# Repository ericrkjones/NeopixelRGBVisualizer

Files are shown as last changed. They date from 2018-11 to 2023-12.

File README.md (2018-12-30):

# NeopixelRGBVisualizer
A Neopixel strand visualizer for an audio input that maps frequency distribution to color.  

# Modes
The device has multiple display modes.  To change modes, press the "M" button.

# Settings
To change the settings, press and hold the "M" button for 3 seconds.  The first light in the strand will change color to indicate the setting that will be adjusted.  Press the "M" button again to cycle to the next setting.  After cycling through all the setting modes, the settings will be stored for the next time you plug the device in.  

## Length
When the light is red, press the plus and minus buttons to change the length of the strand.  The strand is made of Neopixels, so it can be cut short (while the power is off) if you need it to be shorter.  To reset to the default 50 lights, press and hold both the plus and minus button at the same time.  

## Gain
When the light is green, press the plus and minus buttons to change the input gain.  Adjusting the gain up is possible but not recommended because the noise will be amplified.  Adjusting the noise down may be necessary.  If the appropriate gain cannot be set, external hardware may be required.  To reset to the default gain, press and hold both the plus and minus button at the same time.

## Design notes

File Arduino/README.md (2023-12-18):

# Hardware notes

The manufactured versions of this board use an atmega328p**b** not the typical atmega328p, you will therefore need to make sure your programmer knows this. If you are using `avrdude` you can do this wihh the parameter `-patmega328pb` for example `/usr/bin/avrdude -C/etc/avrdude.conf -v -patmega328pb -cstk500v1 -P/dev/ttyACM0 -b19200 -Uflash:w:<PATH TO HEX FILE>/MSGEQ7NeopixelTree4.ino.hex:i` or in the arduino IDE add [this](https://github.com/watterott/ATmega328PB-Testing) board file.

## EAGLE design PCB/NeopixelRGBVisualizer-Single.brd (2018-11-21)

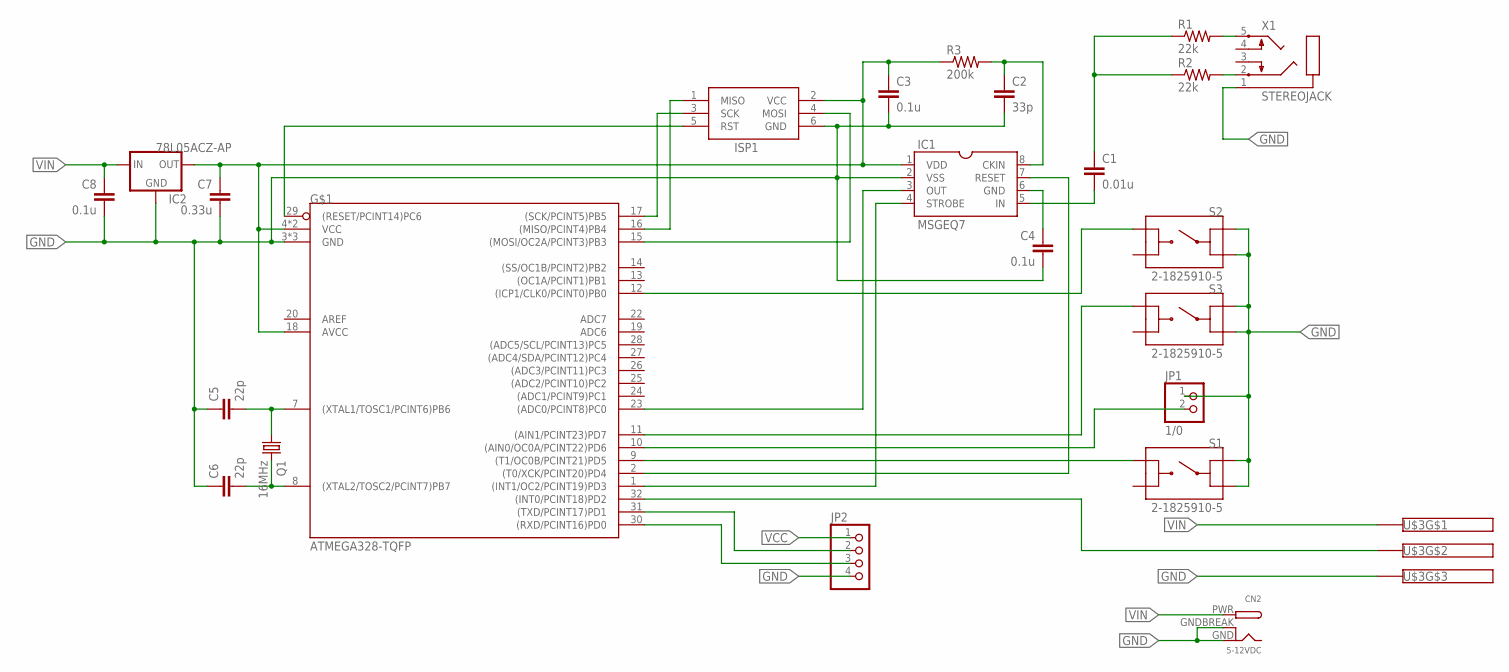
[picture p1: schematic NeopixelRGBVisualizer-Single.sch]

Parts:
C1: 0.01u; C0805
C2: 33p; C0805
C3, C4, C8: 0.1u; C0805
C5, C6: 22p; C0805
C7: 0.33u; C0805
CN2: 5-12VDC; DCJACK_2MM_PTH
IC1: MSGEQ7; DIL08
IC2: 78L05ACZ-AP; 78LXX
ISP1: AVRISP-6; AVRISP
JP1: 1/0; 1X02-ROUND
JP2: PINHD-1X4/OCT; 1X04-OCT
Q1: 16MHz; CTS406
R1, R2: 22k; M0805
R3: 200k; M0805
S1, S2, S3: 2-1825910-5; SW_2-1825910
U$1: ATMEGA328-TQFP; 32M1-A
U$3: 0039303035; 4.2MM-3PIN
X1: STEREOJACK; STX3100

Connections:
GND: C2.2, C3.2, C4.2, C5.1, C6.1, C7.2, C8.2, CN2.GND, CN2.GNDBREAK, IC1.2 (VSS), IC2.GND, ISP1.6 (GND), JP1.1, JP2.4, S1.1, S1.3, S2.1, S2.3, S3.1, S3.3, U$1.3 (GND), U$1.5 (GND), U$1.21 (GND), U$3.P$3, X1.1
MSGEQ7_OUT: IC1.3 (OUT), U$1.23 ((ADC0/PCINT8)PC0)
MSGEQ7_RESET: IC1.7 (RESET), U$1.2 ((T0/XCK/PCINT20)PD4)
MSGEQ7_STROBE: IC1.4 (STROBE), U$1.1 ((INT1/OC2/PCINT19)PD3)
unnamed: ISP1.3 (SCK), U$1.17 ((SCK/PCINT5)PB5)
unnamed: ISP1.5 (RST), U$1.29 ((RESET/PCINT14)PC6)
unnamed: ISP1.1 (MISO), U$1.16 ((MISO/PCINT4)PB4)
unnamed: ISP1.4 (MOSI), U$1.15 ((MOSI/OC2A/PCINT3)PB3)
unnamed: C4.1, IC1.6 (GND)
unnamed: S3.2, U$1.11 ((AIN1/PCINT23)PD7)
unnamed: C1.2, IC1.5 (IN)
unnamed: R2.2, X1.2
unnamed: C2.1, IC1.8 (CKIN), R3.2
unnamed: R1.2, X1.5
unnamed: C5.2, Q1.1, U$1.7 ((XTAL1/TOSC1/PCINT6)PB6)
unnamed: C6.2, Q1.3 (2), U$1.8 ((XTAL2/TOSC2/PCINT7)PB7)
unnamed: C1.1, R1.1, R2.1
unnamed: U$1.32 ((INT0/PCINT18)PD2), U$3.P$2
unnamed: S2.2, U$1.12 ((ICP1/CLK0/PCINT0)PB0)
unnamed: JP1.2, U$1.10 ((AIN0/OC0A/PCINT22)PD6)
unnamed: S1.2, U$1.9 ((T1/OC0B/PCINT21)PD5)
RX: JP2.3, U$1.30 ((RXD/PCINT16)PD0)
TX: JP2.2, U$1.31 ((TXD/PCINT17)PD1)
VCC: C3.1, C7.1, IC1.1 (VDD), IC2.OUT, ISP1.2 (VCC), JP2.1, R3.1, U$1.4 (VCC), U$1.6 (VCC), U$1.18 (AVCC)
VIN: C8.1, CN2.PWR, IC2.IN, U$3.P$1

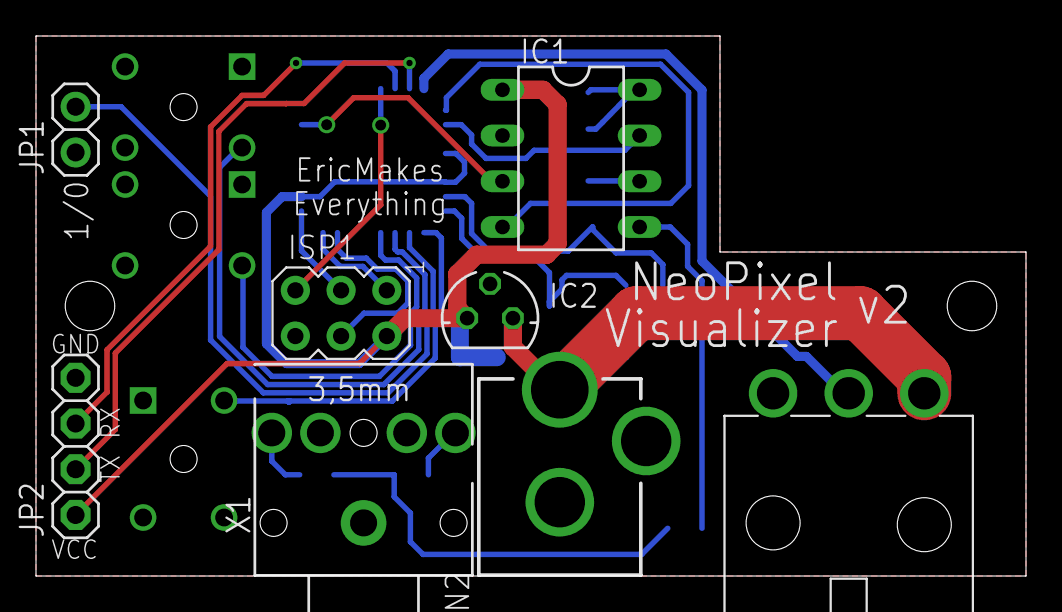
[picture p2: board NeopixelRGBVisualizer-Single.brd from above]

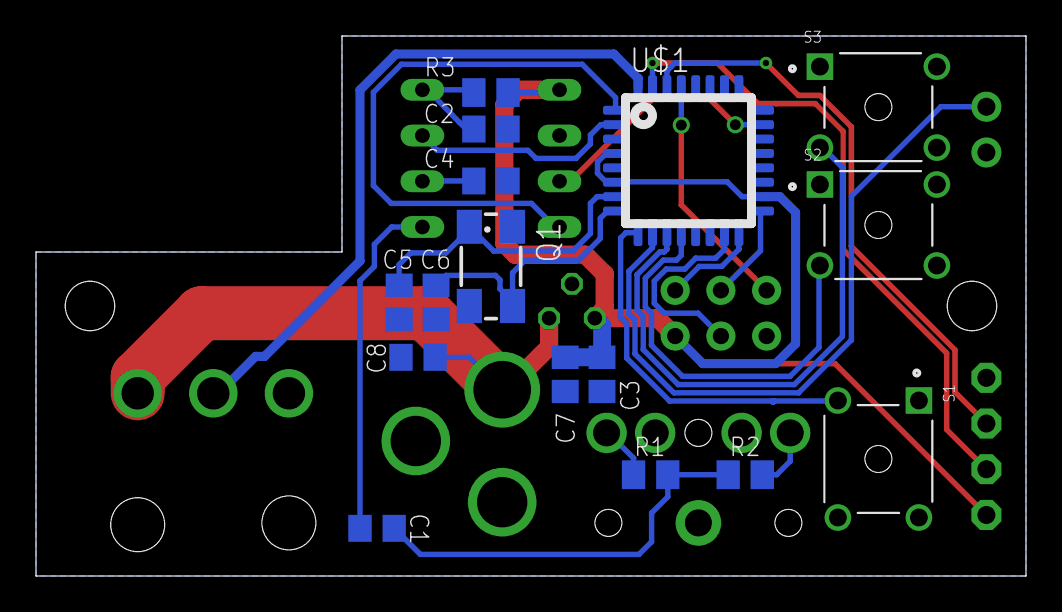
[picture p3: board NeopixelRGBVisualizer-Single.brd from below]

Board: 2 copper layers, 55.0 x 30.0 mm, 24 parts (16 on the bottom side), 25 nets.

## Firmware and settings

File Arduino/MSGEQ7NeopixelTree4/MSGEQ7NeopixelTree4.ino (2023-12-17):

// Import NicoHood's MSGEQ7 driver
#include <MSGEQ7.h>
#include <EEPROM.h>
//
#include "MSGEQ7NeopixelTree4.h"
/*
  Persistant customization variables
*/

#define CONFIG_DELAY 50
// Length of the Neopixel display
unsigned long length = 50;
const unsigned long defaultlength = 50;
const int length_eepromaddress = 0;
// Global input linear gain as a fraction of 255
unsigned long gain = 240;
const int gain_eepromaddress = 4;
const long defaultgain = 240;
// Maximum and minimum brightness per channel
byte maxbrightness = 100; 
const byte defaultmaxbrightness = 100;
byte minbrightness = 5;
const byte defaultminbrightness = 5;
// Color 1 for use in fixed-color displays, RGB order
word hue1 = 0;
const int defaulthue1 = 0;
// Color 2 for use in fixed color displays, RGB order
word hue2 = 255;
const byte defaulthue2 = 255;
/*
  Permutation index of RGB for all-color displays.
  0: RGB
  1: GBR
  2: BRG
  3: RBG
  4: GRB
  5: BGR
  Notice that 0-2 are rotated RGB order and 3-5 are rotated RBG order
  So, for any moving displays that use a fade through all colors,
  all that matters is those ranges.
*/
byte rgbpermutationindex;
const byte defaultrgbperumtationindex = 0;
// Speed for scrolling displays in units of milliseconds/dot
byte speed;
const byte defaultspeed = 30;
// 0-index point for bar-style displays
unsigned long startpoint;
const long defaultstartpoint = 0;
// Operating mode
byte mode = 0;

// Global variables

// Define Neopixel connection
Adafruit_NeoPixel strip = Adafruit_NeoPixel(length, STRIP_PIN, NEO_RGB + NEO_KHZ800);

// Define MSGEQ7 connection
CMSGEQ7<MSGEQ7_SMOOTH, MSGEQ7_PINRESET, MSGEQ7_PINSTROBE, MSGEQ7_PINDCIN> MSGEQ7;

// Frequency volume values
byte freqVolume[MSGEQ7_FREQCOUNT];
long meanVolume = 0;

// Button variables
bool button_mode;
bool button_mode_last = 0;
bool button_mode_rising = 0;
bool button_mode_falling = 0;
unsigned long button_mode_start_time = 0;
unsigned long button_mode_held_time;
bool button_minus;
bool button_minus_last = 0;
bool button_minus_rising = 0;
bool button_minus_falling = 0;
unsigned long button_minus_start_time = 0;
unsigned long button_minus_held_time;
bool button_plus;
bool button_plus_last = 0;
bool button_plus_rising = 0;
bool button_plus_falling = 0;
unsigned long button_plus_start_time = 0;
unsigned long button_plus_held_time;
bool button_custom;
bool button_custom_last = 0;
bool button_custom_rising = 0;
bool button_custom_falling = 0;
unsigned long button_custom_start_time = 0;
unsigned long button_custom_held_time;
unsigned long config_fastadd_start_time = 0;
unsigned long current_time = 0;

void readbuttons() {
  button_mode = ! digitalRead(BUTTON_MODE);
  button_minus = ! digitalRead(BUTTON_MINUS);
  button_plus = ! digitalRead(BUTTON_PLUS);
  button_custom = ! digitalRead(BUTTON_CUSTOM);
  // Set rising edge booleans
  if (button_mode && ! button_mode_last) {
    button_mode_rising = 1;
  } else {
    if (!button_mode && button_mode_last) {
      button_mode_falling = 1;
    } else {
      button_mode_rising = 0;
      button_mode_falling = 0;
    }
  }
  if (button_minus && ! button_minus_last) {
    button_minus_rising = 1;
  } else {
    if (!button_minus && button_mode_last) {
      button_mode_falling = 1;
    } else {
      button_minus_rising = 0;
      button_minus_falling = 0;
    }
  }
  if (button_plus && ! button_plus_last) {
    button_plus_rising = 1;
  } else {
    if (!button_plus && button_mode_last) {
      button_mode_falling = 1;
    } else {
      button_plus_rising = 0;
      button_plus_falling = 0;
    }
  }
  if (button_custom && ! button_custom_last) {
    button_custom_rising = 1;
  } else {
    if (!button_custom && button_mode_last) {
      button_mode_falling = 1;
    } else {
      button_custom_rising = 0;
      button_custom_falling = 0;
    }
  }
  // Set the last time that the buttons were not pressed
  // Calculate difference in time between now and when buttons were last not pressed
  if (button_mode) {
    button_mode_held_time = current_time - button_mode_start_time;
  } else {
    button_mode_start_time = current_time;
    button_mode_held_time = 0;
  }
  if (button_minus) {
    button_minus_held_time = current_time - button_minus_start_time;
  } else {
    button_minus_start_time = current_time;
    button_minus_held_time = 0;
  }
  if (button_plus) {
    button_plus_held_time = current_time - button_plus_start_time;
  } else {
    button_plus_start_time = current_time;
    button_plus_held_time = 0;
  }
  if (button_custom) {
    button_custom_held_time = current_time - button_custom_start_time;
  } else {
    button_custom_start_time = current_time;
    button_custom_held_time = 0;
  }
  // Set loop variables
  button_mode_last = button_mode;
  button_minus_last = button_minus;
  button_plus_last = button_plus;
  button_custom_last = button_custom;
}

byte coerceToByte(long x) {
  if (x < 0) {
    x = 0;
  } else {
    if (x > 255) {
      x = 255;
    }
  }
  return byte(x);
}

unsigned long eepromReadLong(int address) {
  long value;
  for (int i = 0; i < 4; i++) {
    value = value << 8;
    value += EEPROM.read(address + i);
  }
  return value;
}

void eepromWriteLong(int address, unsigned long value) {
  for (int i = 0; i < 4; i++) {
    EEPROM.update(address + 3 - i, value >> (i * 8));
  }
}

void updateFreqVolume() {
  for (int i = 0; i < MSGEQ7_FREQCOUNT; i++) {
#ifdef MSGEQ7_MAPNOISE
    freqVolume[i] = mapNoise(MSGEQ7.get(i));
#else
    freqVolume[i] = MSGEQ7.get(i);
#endif
  }
}

long getMeanVolume() {
  long y = (MSGEQ7.getVolume() + GAIN_OFFSET) * gain / 255;
  if (y < 0) {
    y = 0;
  }
  return y;
}

void readAudio() {
  updateFreqVolume();
  meanVolume = getMeanVolume();
}

void startNeopixels() {
  strip = Adafruit_NeoPixel(length, STRIP_PIN, NEO_RGB + NEO_KHZ800);
  strip.begin();
  strip.show();
}

// RGBVu functions:

int   rgbvu_red0   = 0;
int rgbvu_green0   = 0;
int  rgbvu_blue0   = 0;
int   rgbvu_red1[] = {70, 70, 30, 0, 0, 0, 0};
int rgbvu_green1[] = {0, 0, 40, 60, 40, 0, 0};
int  rgbvu_blue1[] = {0, 0, 0, 0, 30, 60, 60};

// RGB values
byte rgbvu_red = 0;
byte rgbvu_green = 0;
byte rgbvu_blue = 0;

long rgbvu_calculateColor(byte sample[], int color1[]) {
  long y = 0;
  for (int i = 0; i < MSGEQ7_FREQCOUNT; i++) {
    y += sample[i] * color1[i];
  }
  return y;
}

void rgbvu_normalizeColors() {
  long r = rgbvu_calculateColor(freqVolume, rgbvu_red1) / 255 + rgbvu_red0;
  long g = rgbvu_calculateColor(freqVolume, rgbvu_green1) / 255 + rgbvu_red0;
  long b = rgbvu_calculateColor(freqVolume, rgbvu_blue1) / 255 + rgbvu_red0;
  long sum = r + g + b;
  rgbvu_red = coerceToByte(maxbrightness * r / sum);
  rgbvu_green = coerceToByte(maxbrightness * g / sum);
  rgbvu_blue = coerceToByte(maxbrightness * b / sum);
}
void rgbvu_output() {
  for (int i = 0; i < length; i++) {
    if (i < meanVolume) {
      strip.setPixelColor(i, strip.Color(rgbvu_red, rgbvu_green, rgbvu_blue));
    } else {
      strip.setPixelColor(i, strip.Color(minbrightness, minbrightness, minbrightness));
    }
  }
}

void visualizer_rgbvu() {
  // 0th order polynomial coefficient
  // This is not broken out because, when the dependent terms are summed, that would waste time
  rgbvu_normalizeColors();
  rgbvu_output();
  strip.show();
}

void visualizer_config_rgbvu(byte color[]) {
  // 0th order polynomial coefficient
  // This is not broken out because, when the dependent terms are summed, that would waste time
  rgbvu_normalizeColors();
  rgbvu_output();
  strip.setPixelColor(0, strip.Color(color[0], color[1], color[2]));
  strip.show();
}

void setup() {
  // Set pinmode for buttons
  pinMode(BUTTON_MODE, INPUT_PULLUP);
  pinMode(BUTTON_MINUS, INPUT_PULLUP);
  pinMode(BUTTON_PLUS, INPUT_PULLUP);
  pinMode(BUTTON_CUSTOM, INPUT_PULLUP);

  //  // Read EEPROM
  length = eepromReadLong(length_eepromaddress);
  gain = eepromReadLong(gain_eepromaddress);

  if (length > 65534) {
    length = defaultlength;
    eepromWriteLong(length_eepromaddress, length);
  }
  if (gain > 1020) {
    gain = defaultgain;
    eepromWriteLong(gain_eepromaddress, gain);
  }

  
  // Start Neopixels
  startNeopixels();

  // Initialize MSGEQ7
  MSGEQ7.begin();
}


//Rainbow Wheel

unsigned int hue = 0;

// Input a value 0 to 255 to get a color value.
// The colours are a transition r - g - b - back to r.
uint32_t Wheel(unsigned int hue) {
  if (hue > 765) {
    hue -= 765;
  }
  if (hue < 255) {
    return strip.Color(normalizeColor(255 - hue), normalizeColor(hue), 0);
  }
  if (hue < 510) {
    hue -= 255;
    return strip.Color(0, normalizeColor(255 - hue), normalizeColor(hue));
  }
  hue -= 510;
  return strip.Color(normalizeColor(hue), 0, normalizeColor(255 - hue));
}

byte normalizeColor(byte color) {
  word colorout = color * maxbrightness / 255;
  return colorout;
}

void rainbow() {
  for (unsigned int i = 0; i < length; i++) {
    strip.setPixelColor(i, Wheel(length - i - 1 + hue));
  }
  strip.show();
  if (hue == 764) {
    hue = 0;
  } else {
    hue ++;
  }
  delay(10);
}

bool statedelay(unsigned long delaytime) {
  if (current_time - config_fastadd_start_time > delaytime) {
    config_fastadd_start_time = current_time;
    return true;
  } else {
    return false;
  }
}

void loop() {
  current_time = millis();
  bool newReading = MSGEQ7.read();
  readbuttons();
  if (newReading) {
    readAudio();
  }
  if (button_mode_held_time > 3000) {
    mode = 253;
  }
  switch (mode) {
    case 0:
      if (button_mode_rising) {
        mode ++;
      } else {
        if (newReading) {
          visualizer_rgbvu();
        }
      }
      break;
    case 1:
      if (button_mode_rising) {
        mode ++;
      } else {
        if (newReading) {
          rainbow();
        }
      }
      break;
    // Global Length Setting
    case 253:
      if (button_mode_rising) {
        mode ++;
      } else {
        if (button_plus &&  button_minus) {
          if (button_plus_held_time > 5000 && button_minus_held_time > 3000) {
            length = defaultlength;
            startNeopixels();
          }
        } else {
          if (length < 65534) {
            if (button_plus_rising || button_plus_held_time > 3000) {
              if (statedelay(CONFIG_DELAY)) {
                length ++;
                startNeopixels();
              }
            }
          }
          if (length > 1) {
            if (button_minus_rising || button_minus_held_time > 3000) {
              if (statedelay(CONFIG_DELAY)) {
                length --;
                strip.setPixelColor(length, strip.Color(0, 0, 0));
                strip.show();
                startNeopixels();
              }
            }
          }
        }
      }
      if (newReading) {
        byte configcolor[] = {250, 0, 0};
        visualizer_config_rgbvu(configcolor);
      }
      break;
    // Global gain setting
    case 254:
      if (button_mode_rising) {
        mode ++;
      } else {
        if (button_plus &&  button_minus) {
          if (button_plus_held_time > 5000 && button_minus_held_time > 3000) {
            gain = defaultgain;
          }
        } else {
          if (gain < 1020) {
            if (button_plus_rising || button_plus_held_time > 500) {
              if (statedelay(CONFIG_DELAY)) {
                gain ++;
              }
            }
          }
          if (gain > 1) {
            if (button_minus_rising || button_minus_held_time > 500) {
              if (statedelay(CONFIG_DELAY)) {
                gain --;
              }
            }
          }
        }
      }
      if (newReading) {
        byte configcolor[] = {0, 250, 0};
        visualizer_config_rgbvu(configcolor);
      }
      break;
    case 255:
      eepromWriteLong(length_eepromaddress, length);
      eepromWriteLong(gain_eepromaddress, gain);
      mode ++;
      break;
    default:
      mode = 0;
  }
}

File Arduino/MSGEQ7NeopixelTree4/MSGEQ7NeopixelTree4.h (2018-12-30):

//Header file for NeopixelRGBVisualizer v2

//#define DEBUG
#define NEOPIXEL_ENABLE

#ifdef NEOPIXEL_ENABLE
#include <Adafruit_NeoPixel.h>
#define STRIP_PIN 2
#endif

// Import NicoHood's MSGEQ7 driver
#include <MSGEQ7.h>
// Number of channels of MSGEQ7 output
#define MSGEQ7_FREQCOUNT 7
// Analog input connected to the MSGEQ7 DC voltage pin
#define MSGEQ7_PINDCIN A0
// Digital output connected to the MSGEQ7 reset pin
#define MSGEQ7_PINRESET 4
// Digital output connected to the MSGEQ7 strobe pin
#define MSGEQ7_PINSTROBE 3
// Sample Interval of the MSGEQ7
#define MSGEQ7_INTERVAL 33333 // 1000000/30
// MSGEQ7 output mean filter rank
#define MSGEQ7_SMOOTH 10
// Reduction of mean volume for silence:
#define GAIN_OFFSET -1

// Button count
#define BUTTONCOUNT 4
// Digital input switched low by the "Mode" button
#define BUTTON_MODE 5
// Digital input switched low by the "-" button
#define BUTTON_MINUS 8
// Digital input switched low by the "+" button
#define BUTTON_PLUS 7
// Digital input switched low by the "I/O" header pins
#define BUTTON_CUSTOM 6

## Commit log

2018-01-01 Created Arduino code.
2018-04-16 Eagle CAD for single-channel design.
    [NeopixelRGBVisualizer-Single.brd, NeopixelRGBVisualizer-Single.sch]
2018-10-24 Version of board sent out for prototyping. Can connect with avrdude, having some other issues.
    [NeopixelRGBVisualizer-Single.brd, NeopixelRGBVisualizer-Single.sch]
2018-10-31 Almost ready for second prototype order -Added 3 tactile buttons for control inputs: "Power","+","-" -Changed Phoenix screw terminal to Molex Mini-Fit Jr receptacle -Added small potentiometer as inpu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
    [NeopixelRGBVisualizer-Single.brd, NeopixelRGBVisualizer-Single.sch]
2018-10-31 Reverted to first prototype, designing second prototype using updated libraries.
    [NeopixelRGBVisualizer-Single.brd, NeopixelRGBVisualizer-Single.sch]
2018-11-01 Updated broken ATMega328PB footprint. This was caused by some Eagle glitch.
    [NeopixelRGBVisualizer-Single.brd, NeopixelRGBVisualizer-Single.sch]
2018-11-01 Very tight design, needs to be fit into a larger enclosure.
    [NeopixelRGBVisualizer-Single.brd, NeopixelRGBVisualizer-Single.sch]
2018-11-02 Reorganized and resized board to match new project box dimensions.
    [NeopixelRGBVisualizer-Single.brd]
2018-11-04 Prototype version 2 with buttons and Molex minifit jr connector with shape appropriate for project boxes
    [NeopixelRGBVisualizer-Single.brd, NeopixelRGBVisualizer-Single.sch]
2018-11-04 Partially completed silkscreen for v2 production
    [NeopixelRGBVisualizer-Single.brd, NeopixelRGBVisualizer-Single.sch]
2018-11-05 Resized board to try to sqeeze it into the project box easier, made a cutout section for a big friendly panel-mount power button, and moved descriptive text from the tdocu layer to the tnames layer t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
    [NeopixelRGBVisualizer-Single.brd]
2018-11-05 Updated Arduino code to work with Arduino core AVR board tools.
2018-11-20 Updated board to have correct footprints for tactile switches and potentiometer, since footprints acquired from SnapEDA were wrong.
    [NeopixelRGBVisualizer-Single.brd, NeopixelRGBVisualizer-Single.sch]
2018-11-21 Found problem in proto2 board to be caused by knockoff MSGEQ7 chip. Maintained fixed pinouts of tactile switches and removed potentiometer from board. Electrically, that circuit did not serve its pur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
    [NeopixelRGBVisualizer-Single.brd, NeopixelRGBVisualizer-Single.sch]
2018-11-21 Added headers to access serial TX/RX pins, power, and GND. Requried 2 more vias.
    [NeopixelRGBVisualizer-Single.brd, NeopixelRGBVisualizer-Single.sch]
2018-11-21 Moved Tx/Rx traces to increase clearance from pads.
    [NeopixelRGBVisualizer-Single.brd]
2018-12-30 Added arduino code.
